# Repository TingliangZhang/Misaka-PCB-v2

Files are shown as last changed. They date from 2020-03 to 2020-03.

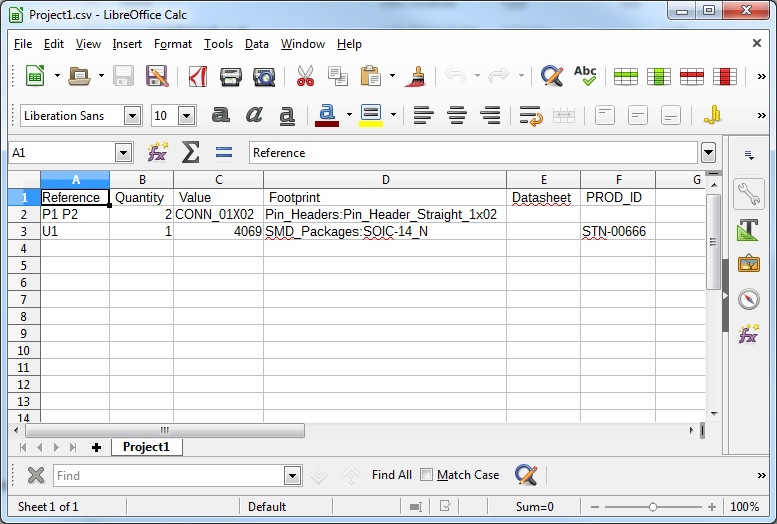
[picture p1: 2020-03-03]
KiCAD Lib/SparkFun-KiCad-Libraries/Tools/SparkFun-Eagle-Libraries_Conversion/generatedBOM.jpg

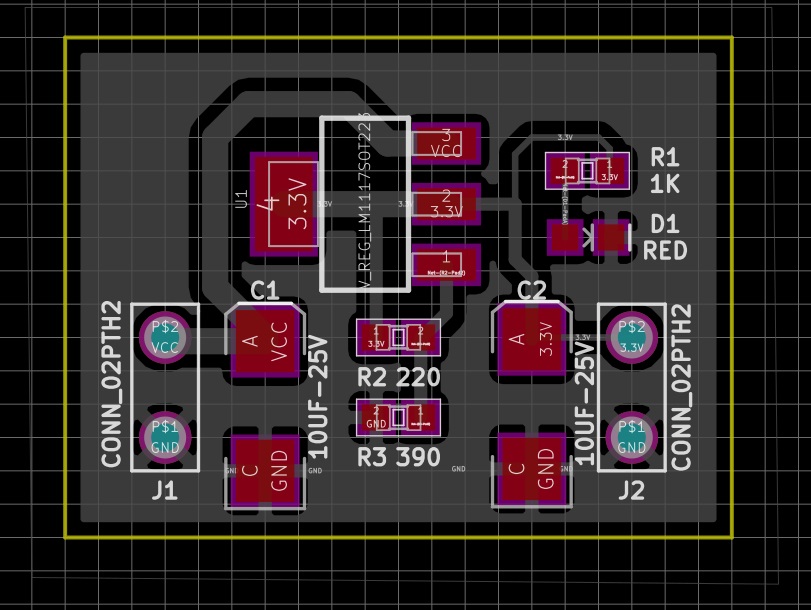
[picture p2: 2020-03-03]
KiCAD Lib/SparkFun-KiCad-Libraries/Tools/SparkFun-Eagle-Libraries_Conversion/example4.jpg

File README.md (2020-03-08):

# Misaka-PCB-v2

Second Version of [TingliangZhang](https://github.com/TingliangZhang)/**[Misaka-PCB](https://github.com/TingliangZhang/Misaka-PCB)**

Using [KiCad EDA](https://kicad-pcb.org/)

插件安装等参考TUNA的帮助：

https://mirrors.tuna.tsinghua.edu.cn/help/kicad/

## CSV File (BOM)

需要将 ; 批量替换成 , 

## Keyboard commands - hotkeys

Many commands are accessible directly with the keyboard. Selection can be either upper or lower case. Most hot keys are shown in menus. Some hot keys that do not appear are:

- `Delete`: deletes a footprint or a track. (*Available only if the Footprint mode or the Track mode is active*)
- `V`: if the track tool is active switches working layer or place via, if a track is in progress.
- `+` and `-`: select next or previous layer.
- `?`: display the list of all hot keys.
- `Space`: reset relative coordinates.

## Third Party Libraries

In addition to the official KiCad libraries, there are other, third party sources for KiCad library packages.

While the following links may be useful sources of library packages, they are not maintained or endorsed by the KiCad project.

### Digi-Key

[Digi-Key](https://www.digikey.com/) maintains an atomic parts library for KiCad on their [GitHub page](https://github.com/digikey/digikey-kicad-library/). These libraries are licensed under an agreement similar to the official libraries.

### SparkFun

[SparkFun Electronics](https://sparkfun.com/) provide KiCad library files for many of their products on their [GitHub page](https://github.com/sparkfun/SparkFun-KiCad-Libraries). These libraries are based on the SparkFun Eagle libraries.

### SnapEDA

[SnapEDA](https://www.snapeda.com/) provides KiCad symbol and footprint libraries for their customers. The libraries are freely available and can be found on their [KiCad library page](https://www.snapeda.com/kicad). The library license can be found on their [terms of service page](https://www.snapeda.com/about/terms).

### Import Steps For KiCad 5 and Newer

https://www.snapeda.com/

1. In KiCad, go to *Tools > Edit PCB Footprints*.
2. Click on *Preferences > Manage Footprint Libraries*.

#### *For version 5.0*

In the *Global Libraries* tab, click on *Browse Libraries* and navigate to the downloaded folder after unzipping the .zip file. Then click *OK*.

1. Click on *Load footprint from library > Select by Browser*.
2. Navigate to the library folder you imported.
3. Double-click on the footprint to open it.

#### *For version 5.1*

In the *Global Libraries* tab, click on *Add existing library to table*, the small folder icon, and navigate to the downloaded folder after unzipping the .zip file. Then click *OK*.

1. Go to the libraries menu on the left side.
2. Navigate to the library folder you imported.
3. Click on it to open the drop-down menu and double-click on the footprint.

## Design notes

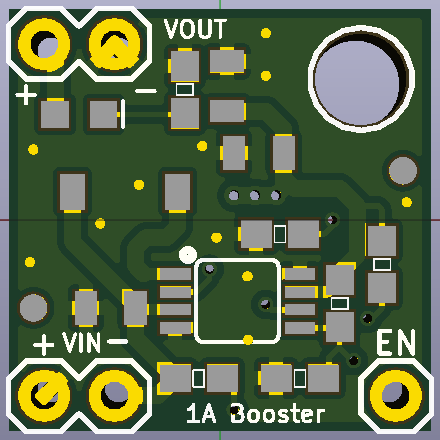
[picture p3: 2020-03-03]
KiCAD Lib/SparkFun-KiCad-Libraries/Documentation/Pictures/ExampleGreen3DView.png

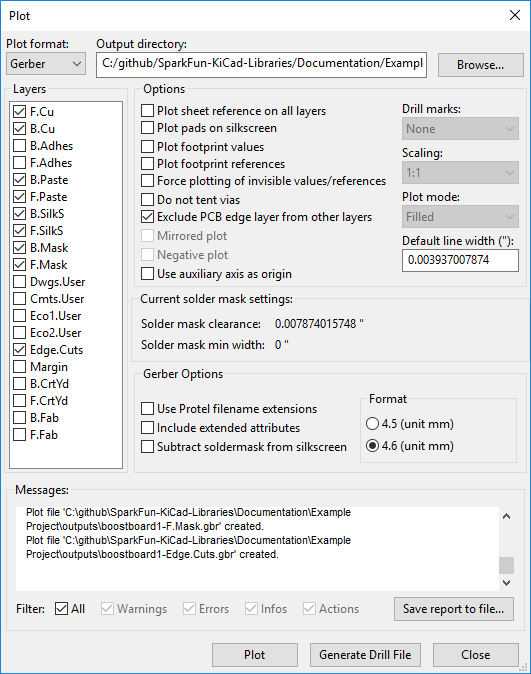
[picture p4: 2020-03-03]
KiCAD Lib/SparkFun-KiCad-Libraries/Documentation/Pictures/PlotSettings.png

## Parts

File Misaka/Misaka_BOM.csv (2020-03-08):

Comment | Description | Designator | Footprint | LibRef | Pins | Quantity | PartNumber | url
22pF | desc | C13, | C_0603_1608Metric_Pad1.05x0.95mm_HandSolder | libref | 2 | 1
1uF | desc | C16,C15, | C_0603_1608Metric_Pad1.05x0.95mm_HandSolder | libref | 2 | 2
100nF | desc | C24,C23,C22,C21,C20,C19,C18,C17,C14,C12,C11,C10, | C_0603_1608Metric_Pad1.05x0.95mm_HandSolder | libref | 2 | 12
47uF | desc | CP5,CP4, | CP_Elec_6.3x5.8 | libref | 2 | 2
CD1206 | desc | D1, | D_1206_3216Metric_Pad1.42x1.75mm_HandSolder | libref | 2 | 1
WS2812B | desc | D10,D9,D8,D7,D6,D5,D4,D3, | LED_WS2812B_PLCC4_5.0x5.0mm_P3.2mm | libref | 4 | 8
M7 | desc | D2, | D_SMA_Handsoldering | libref | 2 | 1
10k | desc | R23, | R_0603_1608Metric_Pad1.05x0.95mm_HandSolder | libref | 2 | 1
1M | desc | R26, | R_0603_1608Metric_Pad1.05x0.95mm_HandSolder | libref | 2 | 1
4.7k | desc | R32,R31,R30,R29, | R_0603_1608Metric_Pad1.05x0.95mm_HandSolder | libref | 2 | 4
1k | desc | R35,R34,R33,R28,R25,R24,R22, | R_0603_1608Metric_Pad1.05x0.95mm_HandSolder | libref | 2 | 7
TACTILE_SWITCH_SMD_4.5MM | desc | S1, | TACTILE_SWITCH_SMD_4.5MM | libref | 4 | 1
LED | desc | TX1,RX1,L1, | LED_0603_1608Metric_Pad1.05x0.95mm_HandSolder | libref | 2 | 3
ATmega2560-16AU | desc | U2, | TQFP-100_14x14mm_P0.5mm | libref | 100 | 1
CH340C | desc | U5, | SOIC-16_3.9x9.9mm_P1.27mm | libref | 16 | 1
AMS1117-5.0 | desc | U6, | SOT-223-3_TabPin2 | libref | 4 | 1
AMS1117-3.3 | desc | U7, | SOT-223-3_TabPin2 | libref | 4 | 1
0.1uF | desc | C-VMB3,C-VMB2,C-VMB1,C-VMA3,C-VMA2,C-VMA1,C8,C5,C2, | C_0603_1608Metric_Pad1.05x0.95mm_HandSolder | libref | 2 | 9
0.01uF | desc | C7,C4,C1, | C_0603_1608Metric_Pad1.05x0.95mm_HandSolder | libref | 2 | 3
0.47uF | desc | C9,C6,C3, | C_0603_1608Metric_Pad1.05x0.95mm_HandSolder | libref | 2 | 3
100uF | desc | CP3,CP2,CP1, | CP_EIA-3528-21_Kemet-B_Pad1.50x2.35mm_HandSolder | libref | 2 | 3
50K | desc | R15,R8,R2, | R_0603_1608Metric_Pad1.05x0.95mm_HandSolder | libref | 2 | 3
30K | desc | R16,R9,R3, | R_0603_1608Metric_Pad1.05x0.95mm_HandSolder | libref | 2 | 3
1M | desc | R17,R10,R1, | R_0603_1608Metric_Pad1.05x0.95mm_HandSolder | libref | 2 | 3
10K | desc | R21,R20,R14,R13,R7,R6, | R_0603_1608Metric_Pad1.05x0.95mm_HandSolder | libref | 2 | 6
200m | desc | R4,R19,R18,R12,R11,R5, | R_0603_1608Metric_Pad1.05x0.95mm_HandSolder | libref | 2 | 6
SW_DIP_x03 | desc | SW1, | SW_DIP_SPSTx03_Slide_6.7x9.18mm_W8.61mm_P2.54mm_LowProfile | libref | 6 | 1
Through Hole Items
Conn_02x03_Odd_Even | desc | ICSP1, | PinHeader_2x03_P2.54mm_Vertical | libref | 6 | 1
Conn_Coaxial_Power | desc | J1, | AMASS_XT30PW-M_1x02_P2.50mm_Horizontal | libref | 4 | 1
USB_B_Micro | desc | J5, | USB_Micro-B_Wuerth_614105150721_Vertical | libref | 7 | 1
Conn_01x04_Female | desc | J6, | PinHeader_1x04_P2.54mm_Vertical | libref | 4 | 1
Conn_01x04_Female_UART | desc | J7, | PinSocket_1x04_P2.54mm_Vertical | libref | 4 | 1
Conn_01x07 | desc | J9, | PinSocket_1x07_P2.54mm_Vertical | libref | 7 | 1
XB24CZ7PIT-004 | desc | MOD1, | XBEE_PRO-20_THT | libref | 20 | 1
24LC02 | desc | U8, | DIP-8_W7.62mm_Socket_LongPads | libref | 8 | 1
CSTLS16M0X51-B0 | desc | Y1, | Resonator_muRata_CSTLSxxxX-3Pin_W5.5mm_H3.0mm | libref | 3 | 1
Conn_01x04_Male | desc | J4,J3,J2, | Molex_PicoBlade_53047-0410_1x04_P1.25mm_Vertical | libref | 4 | 3
Conn_02x04_Odd_Even | desc | J8, | PinSocket_2x04_P1.27mm_Vertical | libref | 8 | 1
DRV8825PWPR | desc | U4,U3,U1, | HTSSOP-28-1EP_4.4x9.7mm_P0.65mm_EP3.4x9.5mm_ThermalVias | libref | 58 | 3

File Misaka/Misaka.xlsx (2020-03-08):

Prj: | Misaka.xml |  |  |  |  |  | Board Qty: | 100
Co.: |  |  |  |  |  |  | Unit Cost: | $0.00
Prj date: | 08/03/2020 16:31:49 |  |  |  |  |  | Total Cost: | $0.00 |  |  |  | $0.00 | 0 |  |  |  | $0.00 | 0 |  |  |  | $0.00 | 0 |  |  |  | $0.00 | 0 |  |  |  | $0.00 | 0 |  |  |  | $0.00 | 0
$ date: | 2020-03-08 16:35:06
Global Part Info |  |  |  |  |  |  |  |  | Digi-Key |  |  |  |  | Farnell |  |  |  |  | LCSC |  |  |  |  | Mouser |  |  |  |  | Newark |  |  |  |  | RS Components
Refs | Value | Desc | Footprint | Manf | Manf# | Qty | Unit$ | Ext$ | Avail | Purch | Unit$ | Ext$ | Cat# | Avail | Purch | Unit$ | Ext$ | Cat# | Avail | Purch | Unit$ | Ext$ | Cat# | Avail | Purch | Unit$ | Ext$ | Cat# | Avail | Purch | Unit$ | Ext$ | Cat# | Avail | Purch | Unit$ | Ext$ | Cat#
C1,C4,C7 | 0.01uF |  | C_0603_1608Metric_Pad1.05x0.95mm_HandSolder |  |  | 0 | $0.00 | $0.00
C13 | 22pF |  | C_0603_1608Metric_Pad1.05x0.95mm_HandSolder |  |  | 0 | $0.00 | $0.00
C15,C16 | 1uF |  | C_0603_1608Metric_Pad1.05x0.95mm_HandSolder |  |  | 0 | $0.00 | $0.00
C2,C5,C8,C-VMA1-C-VMA3,C-VMB1-C-VMB3 | 0.1uF |  | C_0603_1608Metric_Pad1.05x0.95mm_HandSolder |  |  | 0 | $0.00 | $0.00
C3,C6,C9 | 0.47uF |  | C_0603_1608Metric_Pad1.05x0.95mm_HandSolder |  |  | 0 | $0.00 | $0.00
C10-C12,C14,C17-C24 | 100nF |  | C_0603_1608Metric_Pad1.05x0.95mm_HandSolder |  |  | 0 | $0.00 | $0.00
CP4,CP5 | 47uF |  | CP_Elec_6.3x5.8 |  |  | 0 | $0.00 | $0.00
CP1-CP3 | 100uF |  | CP_EIA-3528-21_Kemet-B_Pad1.50x2.35mm_HandSolder |  |  | 0 | $0.00 | $0.00
D1 | CD1206 |  | D_1206_3216Metric_Pad1.42x1.75mm_HandSolder |  |  | 0 | $0.00 | $0.00
D2 | M7 |  | D_SMA_Handsoldering |  |  | 0 | $0.00 | $0.00
D3-D10 | WS2812B |  | LED_WS2812B_PLCC4_5.0x5.0mm_P3.2mm |  |  | 0 | $0.00 | $0.00
ICSP1 | Conn_02x03_Odd_Even |  | PinHeader_2x03_P2.54mm_Vertical |  |  | 0 | $0.00 | $0.00
J1 | Conn_Coaxial_Power |  | AMASS_XT30PW-M_1x02_P2.50mm_Horizontal |  |  | 0 | $0.00 | $0.00
J5 | USB_B_Micro |  | USB_Micro-B_Wuerth_614105150721_Vertical |  |  | 0 | $0.00 | $0.00
J6 | Conn_01x04_Female |  | PinHeader_1x04_P2.54mm_Vertical |  |  | 0 | $0.00 | $0.00
J7 | Conn_01x04_Female_UART |  | PinSocket_1x04_P2.54mm_Vertical |  |  | 0 | $0.00 | $0.00
J8 | Conn_02x04_Odd_Even |  | PinSocket_2x04_P1.27mm_Vertical |  |  | 0 | $0.00 | $0.00
J9 | Conn_01x07 |  | PinSocket_1x07_P2.54mm_Vertical |  |  | 0 | $0.00 | $0.00
J2-J4 | Conn_01x04_Male |  | Molex_PicoBlade_53047-0410_1x04_P1.25mm_Vertical |  |  | 0 | $0.00 | $0.00
MOD1 | XB24CZ7PIT-004 | RF TXRX MOD 802.15.4 TRACE ANT | XBEE_PRO-20_THT | Digi International | XB24CZ7PIT-004 (https://www.digi.com/resources/documentation/digidocs/pdfs/90001500.pdf) | 0 | $0.00 | $0.00
R1,R10,R17,R26 | 1M |  | R_0603_1608Metric_Pad1.05x0.95mm_HandSolder |  |  | 0 | $0.00 | $0.00
R2,R8,R15 | 50K |  | R_0603_1608Metric_Pad1.05x0.95mm_HandSolder |  |  | 0 | $0.00 | $0.00
R22,R24,R25,R28,R33-R35 | 1k |  | R_0603_1608Metric_Pad1.05x0.95mm_HandSolder |  |  | 0 | $0.00 | $0.00
R23 | 10k |  | R_0603_1608Metric_Pad1.05x0.95mm_HandSolder |  |  | 0 | $0.00 | $0.00
R3,R9,R16 | 30K |  | R_0603_1608Metric_Pad1.05x0.95mm_HandSolder |  |  | 0 | $0.00 | $0.00
R4,R5,R11,R12,R18,R19 | 200m |  | R_0603_1608Metric_Pad1.05x0.95mm_HandSolder |  |  | 0 | $0.00 | $0.00
R6,R7,R13,R14,R20,R21 | 10K |  | R_0603_1608Metric_Pad1.05x0.95mm_HandSolder |  |  | 0 | $0.00 | $0.00
R29-R32 | 4.7k |  | R_0603_1608Metric_Pad1.05x0.95mm_HandSolder |  |  | 0 | $0.00 | $0.00
S1 | TACTILE_SWITCH_SMD_4.5MM |  | TACTILE_SWITCH_SMD_4.5MM |  |  | 0 | $0.00 | $0.00
SW1 | SW_DIP_x03 |  | SW_DIP_SPSTx03_Slide_6.7x9.18mm_W8.61mm_P2.54mm_LowProfile |  |  | 0 | $0.00 | $0.00
TX1,L1,RX1 | LED |  | LED_0603_1608Metric_Pad1.05x0.95mm_HandSolder |  |  | 0 | $0.00 | $0.00
U1,U3,U4 | DRV8825PWPR | IC MTR DRVR BIPLR 8.2-45V 28SSOP | HTSSOP-28-1EP_4.4x9.7mm_P0.65mm_EP3.4x9.5mm_ThermalVias | Texas Instruments | DRV8825PWPR | 0 | $0.00 | $0.00
U2 | ATmega2560-16AU |  | TQFP-100_14x14mm_P0.5mm |  | http://ww1.microchip.com/downloads/en/DeviceDoc/Atmel-2549-8-bit-AVR-Microcontroller-ATmega640-1280-1281-2560-2561_datasheet.pdf | 0 | $0.00 | $0.00
U5 | CH340C |  | SOIC-16_3.9x9.9mm_P1.27mm |  | http://www.datasheet5.com/pdf-local-2195953 | 0 | $0.00 | $0.00
U6 | AMS1117-5.0 |  | SOT-223-3_TabPin2 |  |  | 0 | $0.00 | $0.00
U7 | AMS1117-3.3 |  | SOT-223-3_TabPin2 |  |  | 0 | $0.00 | $0.00
U8 | 24LC02 |  | DIP-8_W7.62mm_Socket_LongPads |  | http://ww1.microchip.com/downloads/en/DeviceDoc/21709c.pdf | 0 | $0.00 | $0.00
Y1 | CSTLS16M0X51-B0 |  | Resonator_muRata_CSTLSxxxX-3Pin_W5.5mm_H3.0mm |  |  | 0 | $0.00 | $0.00
 |  |  |  |  |  |  | Total Purchase: | $0.00 |  | 0 |  | $0.00 |  |  | 0 |  | $0.00 |  |  | 0 |  | $0.00 |  |  | 0 |  | $0.00 |  |  | 0 |  | $0.00 |  |  | 0 |  | $0.00
KiCost® v.1.1.3 |  |  |  |  |  |  | Purchase description: |  |  | 0 |  |  |  |  | 0 |  |  |  |  | 0 |  |  |  |  | 0 |  |  |  |  | 0 |  |  |  |  | 0
 |  |  |  |  |  |  |  |  |  | 0 |  |  |  |  | 0 |  |  |  |  | 0 |  |  |  |  | 0 |  |  |  |  | 0 |  |  |  |  | 0
 |  |  |  |  |  |  |  |  |  | 0 |  |  |  |  | 0 |  |  |  |  | 0 |  |  |  |  | 0 |  |  |  |  | 0 |  |  |  |  | 0
 |  |  |  |  |  |  |  |  |  | 0 |  |  |  |  | 0 |  |  |  |  | 0 |  |  |  |  | 0 |  |  |  |  | 0 |  |  |  |  | 0
 |  |  |  |  |  |  |  |  |  | 0 |  |  |  |  | 0 |  |  |  |  | 0 |  |  |  |  | 0 |  |  |  |  | 0 |  |  |  |  | 0
 |  |  |  |  |  |  |  |  |  | 0 |  |  |  |  | 0 |  |  |  |  | 0 |  |  |  |  | 0 |  |  |  |  | 0 |  |  |  |  | 0
 |  |  |  |  |  |  |  |  |  | 0 |  |  |  |  | 0 |  |  |  |  | 0 |  |  |  |  | 0 |  |  |  |  | 0 |  |  |  |  | 0
 |  |  |  |  |  |  |  |  |  | 0 |  |  |  |  | 0 |  |  |  |  | 0 |  |  |  |  | 0 |  |  |  |  | 0 |  |  |  |  | 0
 |  |  |  |  |  |  |  |  |  | 0 |  |  |  |  | 0 |  |  |  |  | 0 |  |  |  |  | 0 |  |  |  |  | 0 |  |  |  |  | 0
 |  |  |  |  |  |  |  |  |  | 0 |  |  |  |  | 0 |  |  |  |  | 0 |  |  |  |  | 0 |  |  |  |  | 0 |  |  |  |  | 0
 |  |  |  |  |  |  |  |  |  | 0 |  |  |  |  | 0 |  |  |  |  | 0 |  |  |  |  | 0 |  |  |  |  | 0 |  |  |  |  | 0
 |  |  |  |  |  |  |  |  |  | 0 |  |  |  |  | 0 |  |  |  |  | 0 |  |  |  |  | 0 |  |  |  |  | 0 |  |  |  |  | 0
 |  |  |  |  |  |  |  |  |  | 0 |  |  |  |  | 0 |  |  |  |  | 0 |  |  |  |  | 0 |  |  |  |  | 0 |  |  |  |  | 0
 |  |  |  |  |  |  |  |  |  | 0 |  |  |  |  | 0 |  |  |  |  | 0 |  |  |  |  | 0 |  |  |  |  | 0 |  |  |  |  | 0
 |  |  |  |  |  |  |  |  |  | 0 |  |  |  |  | 0 |  |  |  |  | 0 |  |  |  |  | 0 |  |  |  |  | 0 |  |  |  |  | 0
 |  |  |  |  |  |  |  |  |  | 0 |  |  |  |  | 0 |  |  |  |  | 0 |  |  |  |  | 0 |  |  |  |  | 0 |  |  |  |  | 0
 |  |  |  |  |  |  |  |  |  | 0 |  |  |  |  | 0 |  |  |  |  | 0 |  |  |  |  | 0 |  |  |  |  | 0 |  |  |  |  | 0
 |  |  |  |  |  |  |  |  |  | 0 |  |  |  |  | 0 |  |  |  |  | 0 |  |  |  |  | 0 |  |  |  |  | 0 |  |  |  |  | 0
 |  |  |  |  |  |  |  |  |  | 0 |  |  |  |  | 0 |  |  |  |  | 0 |  |  |  |  | 0 |  |  |  |  | 0 |  |  |  |  | 0
 |  |  |  |  |  |  |  |  |  | 0 |  |  |  |  | 0 |  |  |  |  | 0 |  |  |  |  | 0 |  |  |  |  | 0 |  |  |  |  | 0
 |  |  |  |  |  |  |  |  |  | 0 |  |  |  |  | 0 |  |  |  |  | 0 |  |  |  |  | 0 |  |  |  |  | 0 |  |  |  |  | 0
 |  |  |  |  |  |  |  |  |  | 0 |  |  |  |  | 0 |  |  |  |  | 0 |  |  |  |  | 0 |  |  |  |  | 0 |  |  |  |  | 0
 |  |  |  |  |  |  |  |  |  | 0 |  |  |  |  | 0 |  |  |  |  | 0 |  |  |  |  | 0 |  |  |  |  | 0 |  |  |  |  | 0
 |  |  |  |  |  |  |  |  |  | 0 |  |  |  |  | 0 |  |  |  |  | 0 |  |  |  |  | 0 |  |  |  |  | 0 |  |  |  |  | 0
 |  |  |  |  |  |  |  |  |  | 0 |  |  |  |  | 0 |  |  |  |  | 0 |  |  |  |  | 0 |  |  |  |  | 0 |  |  |  |  | 0
 |  |  |  |  |  |  |  |  |  | 0 |  |  |  |  | 0 |  |  |  |  | 0 |  |  |  |  | 0 |  |  |  |  | 0 |  |  |  |  | 0
 |  |  |  |  |  |  |  |  |  | 0 |  |  |  |  | 0 |  |  |  |  | 0 |  |  |  |  | 0 |  |  |  |  | 0 |  |  |  |  | 0
 |  |  |  |  |  |  |  |  |  | 0 |  |  |  |  | 0 |  |  |  |  | 0 |  |  |  |  | 0 |  |  |  |  | 0 |  |  |  |  | 0
 |  |  |  |  |  |  |  |  |  | 0 |  |  |  |  | 0 |  |  |  |  | 0 |  |  |  |  | 0 |  |  |  |  | 0 |  |  |  |  | 0
 |  |  |  |  |  |  |  |  |  | 0 |  |  |  |  | 0 |  |  |  |  | 0 |  |  |  |  | 0 |  |  |  |  | 0 |  |  |  |  | 0
 |  |  |  |  |  |  |  |  |  | 0 |  |  |  |  | 0 |  |  |  |  | 0 |  |  |  |  | 0 |  |  |  |  | 0 |  |  |  |  | 0
 |  |  |  |  |  |  |  |  |  | 0 |  |  |  |  | 0 |  |  |  |  | 0 |  |  |  |  | 0 |  |  |  |  | 0 |  |  |  |  | 0
 |  |  |  |  |  |  |  |  |  | 0 |  |  |  |  | 0 |  |  |  |  | 0 |  |  |  |  | 0 |  |  |  |  | 0 |  |  |  |  | 0
 |  |  |  |  |  |  |  |  |  | 0 |  |  |  |  | 0 |  |  |  |  | 0 |  |  |  |  | 0 |  |  |  |  | 0 |  |  |  |  | 0
 |  |  |  |  |  |  |  |  |  | 0 |  |  |  |  | 0 |  |  |  |  | 0 |  |  |  |  | 0 |  |  |  |  | 0 |  |  |  |  | 0
 |  |  |  |  |  |  |  |  |  | 0 |  |  |  |  | 0 |  |  |  |  | 0 |  |  |  |  | 0 |  |  |  |  | 0 |  |  |  |  | 0
 |  |  |  |  |  |  |  |  |  | 0 |  |  |  |  | 0 |  |  |  |  | 0 |  |  |  |  | 0 |  |  |  |  | 0 |  |  |  |  | 0
 |  |  |  |  |  |  |  |  |  | 0 |  |  |  |  | 0 |  |  |  |  | 0 |  |  |  |  | 0 |  |  |  |  | 0 |  |  |  |  | 0
 |  |  |  |  |  |  |  |  |  |  |  |  |  |  |  |  |  |  |  | 0

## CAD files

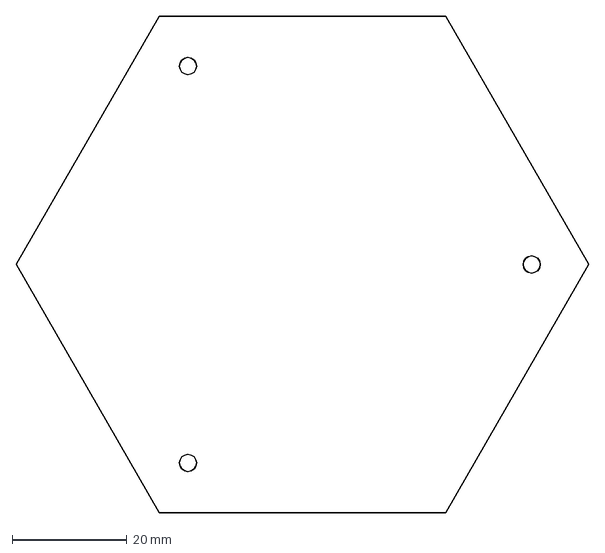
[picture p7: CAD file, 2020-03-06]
Misaka/PCB.dxf
100.0 x 86.6 mm

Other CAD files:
References/MEGA2560_Rev3/dimensioniMega.dxf

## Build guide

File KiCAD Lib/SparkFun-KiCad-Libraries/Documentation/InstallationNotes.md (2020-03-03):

Installation Notes
----------------

* [The KiCad site](http://kicad-pcb.org/)

**KiCad installation**

* Uninstall previous versions of KiCad
* Download KiCad stable version 4.0.5 from [http://kicad-pcb.org/download/](http://kicad-pcb.org/download/windows/) and install
* After install, you'll be prompted to install "Wings 3D", check this box to be redirected to [http://www.wings3d.com/](http://www.wings3d.com/)
* Download and install the stable release 2.1.5

**Using the libraries**

* Create a local project (this is necessary because projects hold library path information)
* Open the "Schematic Library Editor"
* Prefrences -> Component Libraries
  * Remove all libraries from list
  * Add -> navigate to SparkFun-KiCad-Libraries -> select all .lib files -> open, then hit OK
  * Test by selecting an active library.  All sparkfun libraries should be displayed.  Close the library editor
* Open the "PCB Footprint Editor"
* Preferences -> Footprint Library Manager
  * Remove all (if any) libraries, hit OK
* Preferences -> Footprint Libraries Wizard
  * Next (files on my computer)
  * Navigate to SparkFun-KiCad-Libraries -> select all .mod files and hit ok
  * Next
  * Select for this project only
  * Next
  * Close the editor
* Save the project (Green arrow into extern HDD icon, no menu exists)

Now, this project is linked to the libraries.  Open a schematic and place components.  See KiCad enginursday post for converting from schematic into board (Note: You need to have nets for this to work... not just unconnected components)

**License Information**

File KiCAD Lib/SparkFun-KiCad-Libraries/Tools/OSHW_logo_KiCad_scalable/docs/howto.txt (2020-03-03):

How to make your own:
---------------------

Watch / read this first:

* http://www.kicad-pcb.org/display/KICAD/Videos+by+zupnikal

The last two videos should be helpful for how to create a custom .emp file from images.

* http://www.re-innovation.co.uk/web12/index.php/en/blog-75/230-adding-logo-to-kicad

If you use linux (which you should), you don't have to use the online-scaler. Just use the scripts!

---

* Create a folder to hold your new footprint library.
* Copy the scripts 'make_lib.sh' and 'scale.pl' into that folder.
* Make sure these files are executable (chmod u+x ...).
* Copy your custom .emp file into that foler.

* Run the 'make_lib.sh' script as follows:

./make_lib.sh input-file.emp lib-name.mod START END

START and END are placeholders for positive integer numbers (1,2,3...) that determine
the range of created footprint sizes. The units are metric (mm).

The 'lib-name.mod' file will show up in the 'lib' sub-folder. Add it to your pcbnew
library settings as usual.

Footprints that are created for back-layers are automagically mirrored horizontally.
To place them onto a back-layer, hover the mouse-pointer over them and press 'f' for 'flip'.

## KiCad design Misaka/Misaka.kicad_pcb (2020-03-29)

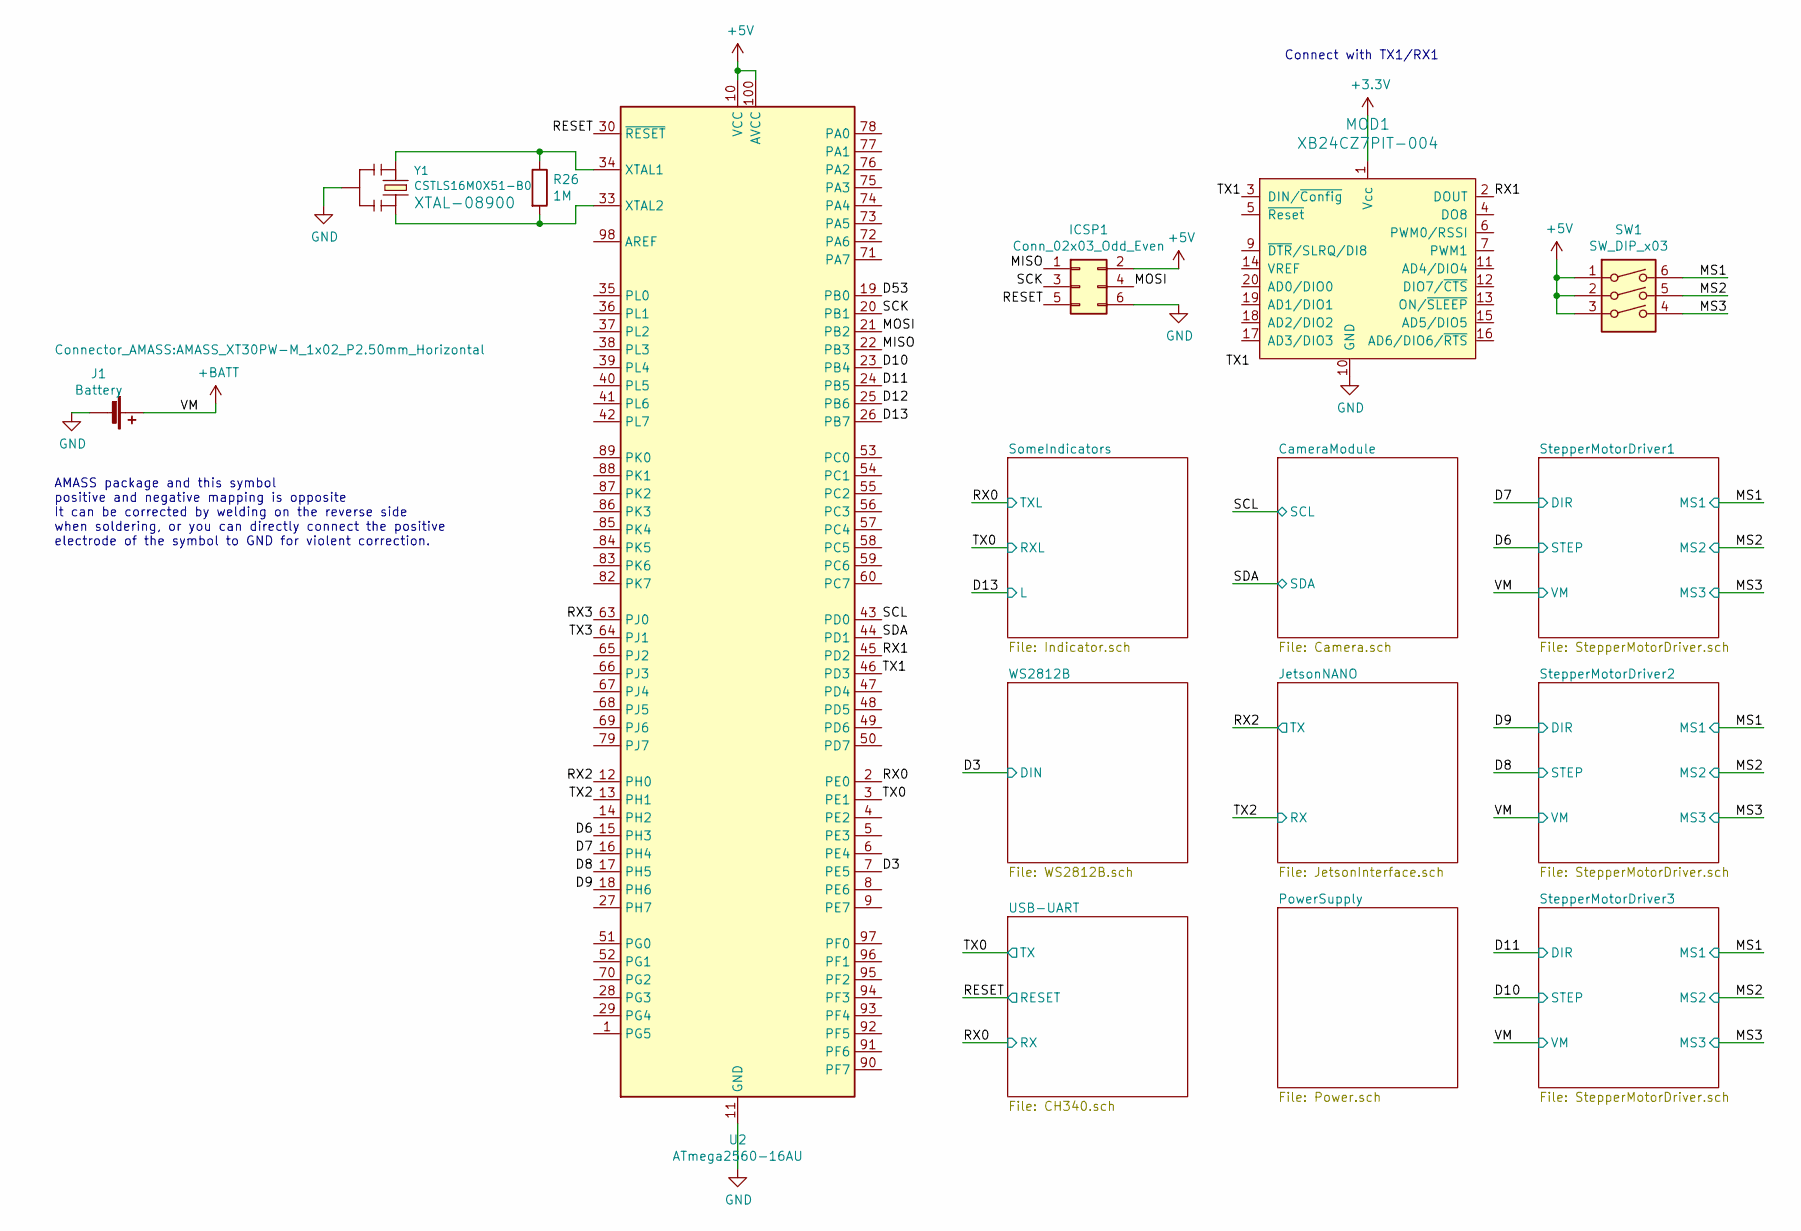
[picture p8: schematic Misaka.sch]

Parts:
ICSP1: Conn_02x03_Odd_Even; PinHeader_2x03_P2.54mm_Vertical
J1: Battery; AMASS_XT30PW-M_1x02_P2.50mm_Horizontal
MOD1: XB24CZ7PIT-004; XBEE_PRO-20_THT; MPN XB24CZ7PIT-004; Digi-Key_PN 602-1557-ND
R26: 1M; R_0603_1608Metric_Pad1.05x0.95mm_HandSolder
SW1: SW_DIP_x03; SW_DIP_SPSTx03_Slide_6.7x9.18mm_W8.61mm_P2.54mm_LowProfile
U2: ATmega2560-16AU; TQFP-100_14x14mm_P0.5mm
Y1: CSTLS16M0X51-B0; Resonator_muRata_CSTLSxxxX-3Pin_W5.5mm_H3.0mm

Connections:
+3V3: MOD1.1 (Vcc); also elsewhere on the board
+5V: ICSP1.2, SW1.1, SW1.2, SW1.3, U2.10 (VCC), U2.31 (VCC), U2.61 (VCC), U2.80 (VCC), U2.100 (AVCC); also elsewhere on the board
+12V: J1.1 (+); also elsewhere on the board
/D3: U2.7 (PE5); also elsewhere on the board
/D6: U2.15 (PH3); also elsewhere on the board
/D7: U2.16 (PH4); also elsewhere on the board
/D8: U2.17 (PH5); also elsewhere on the board
/D9: U2.18 (PH6); also elsewhere on the board
/D10: U2.23 (PB4); also elsewhere on the board
/D11: U2.24 (PB5); also elsewhere on the board
/D13: U2.26 (PB7); also elsewhere on the board
/MISO: ICSP1.1, U2.22 (PB3)
/MOSI: ICSP1.4, U2.21 (PB2)
/MS1: SW1.6; also elsewhere on the board
/MS2: SW1.5; also elsewhere on the board
/MS3: SW1.4; also elsewhere on the board
/RESET: ICSP1.5, U2.30 (~RESET); also elsewhere on the board
/RX0: U2.2 (PE0); also elsewhere on the board
/RX1: MOD1.2 (DOUT), U2.45 (PD2)
/RX2: U2.12 (PH0); also elsewhere on the board
/SCK: ICSP1.3, U2.20 (PB1)
/SCL: U2.43 (PD0); also elsewhere on the board
/SDA: U2.44 (PD1); also elsewhere on the board
/TX0: U2.3 (PE1); also elsewhere on the board
/TX1: MOD1.3 (DIN/~Config), U2.46 (PD3)
/TX2: U2.13 (PH1); also elsewhere on the board
GND: ICSP1.6, J1.2 (-), MOD1.10 (GND), U2.11 (GND), U2.32 (GND), U2.62 (GND), U2.81 (GND), U2.99 (GND), Y1.2; also elsewhere on the board
unnamed: R26.1, U2.34 (XTAL1), Y1.1
unnamed: R26.2, U2.33 (XTAL2), Y1.3

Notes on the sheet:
Connect with TX1/RX1
AMASS package and this symbol positive and negative mapping is opposite It can be corrected by welding on the reverse side when soldering, or you can directly connect the positive electrode of the symbol to GND for violent correction.

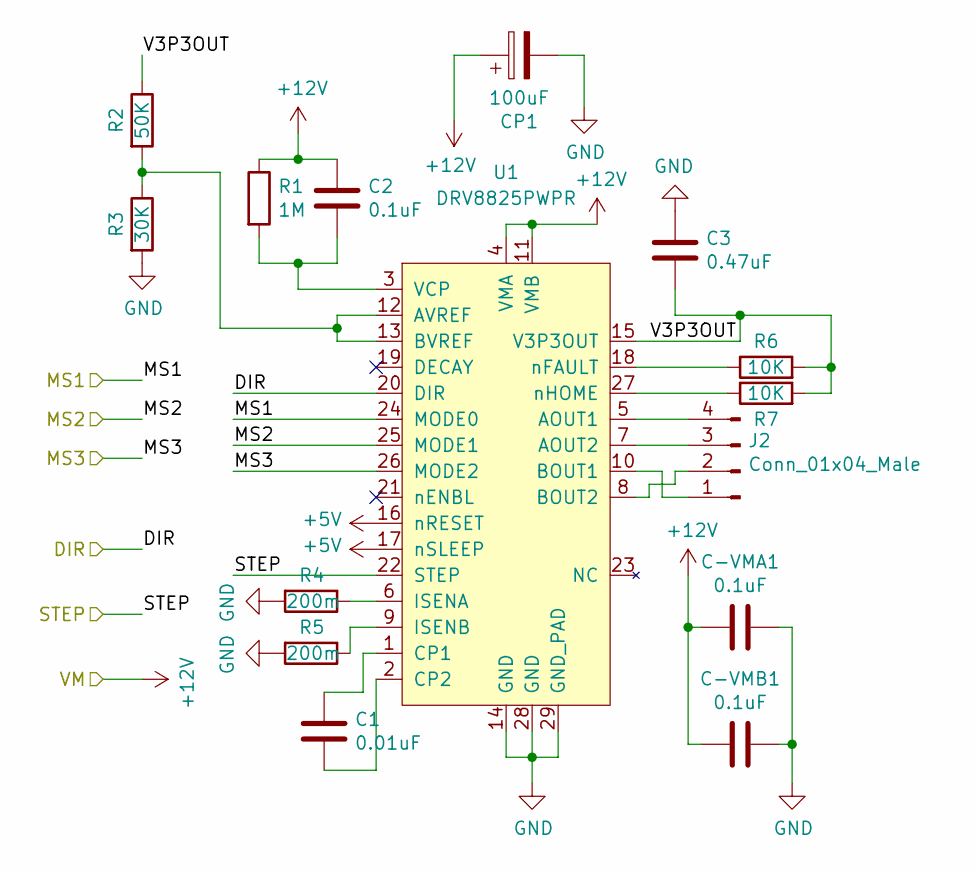
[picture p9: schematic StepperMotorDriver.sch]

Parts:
C1: 0.01uF; C_0603_1608Metric_Pad1.05x0.95mm_HandSolder
C2: 0.1uF; C_0603_1608Metric_Pad1.05x0.95mm_HandSolder
C3: 0.47uF; C_0603_1608Metric_Pad1.05x0.95mm_HandSolder
C-VMA1: 0.1uF; C_0603_1608Metric_Pad1.05x0.95mm_HandSolder
C-VMB1: 0.1uF; C_0603_1608Metric_Pad1.05x0.95mm_HandSolder
CP1: 100uF; CP_EIA-3528-21_Kemet-B_Pad1.50x2.35mm_HandSolder
J2: Conn_01x04_Male; Molex_PicoBlade_53047-0410_1x04_P1.25mm_Vertical
R1: 1M; R_0603_1608Metric_Pad1.05x0.95mm_HandSolder
R2: 50K; R_0603_1608Metric_Pad1.05x0.95mm_HandSolder
R3: 30K; R_0603_1608Metric_Pad1.05x0.95mm_HandSolder
R4, R5: 200m; R_0603_1608Metric_Pad1.05x0.95mm_HandSolder
R6, R7: 10K; R_0603_1608Metric_Pad1.05x0.95mm_HandSolder
U1: DRV8825PWPR; HTSSOP-28-1EP_4.4x9.7mm_P0.65mm_EP3.4x9.5mm_ThermalVias

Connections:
+5V: U1.16 (nRESET), U1.17 (nSLEEP); also elsewhere on the board
+12V: C2.1, C-VMA1.2, C-VMB1.2, CP1.1, R1.1, U1.4 (VMA), U1.11 (VMB); also elsewhere on the board
/D6: U1.22 (STEP); also elsewhere on the board
/D7: U1.20 (DIR); also elsewhere on the board
/MS1: U1.24 (MODE0); also elsewhere on the board
/MS2: U1.25 (MODE1); also elsewhere on the board
/MS3: U1.26 (MODE2); also elsewhere on the board
/StepperMotorDriver1/V3P3OUT: C3.2, R2.1, R6.2, R7.2, U1.15 (V3P3OUT)
GND: C3.1, C-VMA1.1, C-VMB1.1, CP1.2, R3.2, R4.2, R5.2, U1.14 (GND), U1.28 (GND), U1.29 (GND_PAD); also elsewhere on the board
unnamed: C1.1, U1.1 (CP1)
unnamed: C1.2, U1.2 (CP2)
unnamed: C2.2, R1.2, U1.3 (VCP)
unnamed: J2.1, U1.10 (BOUT1)
unnamed: J2.2, U1.8 (BOUT2)
unnamed: J2.3, U1.7 (AOUT2)
unnamed: J2.4, U1.5 (AOUT1)
unnamed: R2.2, R3.1, U1.12 (AVREF), U1.13 (BVREF)
unnamed: R4.1, U1.6 (ISENA)
unnamed: R5.1, U1.9 (ISENB)
unnamed: R6.1, U1.18 (nFAULT)
unnamed: R7.1, U1.27 (nHOME)

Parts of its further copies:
C4, C7: 0.01uF; C_0603_1608Metric_Pad1.05x0.95mm_HandSolder
C5, C8: 0.1uF; C_0603_1608Metric_Pad1.05x0.95mm_HandSolder
C6, C9: 0.47uF; C_0603_1608Metric_Pad1.05x0.95mm_HandSolder
C-VMA2, C-VMA3: 0.1uF; C_0603_1608Metric_Pad1.05x0.95mm_HandSolder
C-VMB2, C-VMB3: 0.1uF; C_0603_1608Metric_Pad1.05x0.95mm_HandSolder
CP2, CP3: 100uF; CP_EIA-3528-21_Kemet-B_Pad1.50x2.35mm_HandSolder
J3, J4: Conn_01x04_Male; Molex_PicoBlade_53047-0410_1x04_P1.25mm_Vertical
R8, R15: 50K; R_0603_1608Metric_Pad1.05x0.95mm_HandSolder
R9, R16: 30K; R_0603_1608Metric_Pad1.05x0.95mm_HandSolder
R10, R17: 1M; R_0603_1608Metric_Pad1.05x0.95mm_HandSolder
R11, R12, R18, R19: 200m; R_0603_1608Metric_Pad1.05x0.95mm_HandSolder
R13, R14, R20, R21: 10K; R_0603_1608Metric_Pad1.05x0.95mm_HandSolder
U3, U4: DRV8825PWPR; HTSSOP-28-1EP_4.4x9.7mm_P0.65mm_EP3.4x9.5mm_ThermalVias

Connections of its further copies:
+5V: U3.16 (nRESET), U3.17 (nSLEEP), U4.16 (nRESET), U4.17 (nSLEEP); also elsewhere on the board
+12V: C5.1, C8.1, C-VMA2.2, C-VMA3.2, C-VMB2.2, C-VMB3.2, CP2.1, CP3.1, R10.1, R17.1, U3.4 (VMA), U3.11 (VMB), U4.4 (VMA), U4.11 (VMB); also elsewhere on the board
/D8: U3.22 (STEP); also elsewhere on the board
/D9: U3.20 (DIR); also elsewhere on the board
/D10: U4.22 (STEP); also elsewhere on the board
/D11: U4.20 (DIR); also elsewhere on the board
/MS1: U3.24 (MODE0), U4.24 (MODE0); also elsewhere on the board
/MS2: U3.25 (MODE1), U4.25 (MODE1); also elsewhere on the board
/MS3: U3.26 (MODE2), U4.26 (MODE2); also elsewhere on the board
/StepperMotorDriver2/V3P3OUT: C6.2, R8.1, R13.2, R14.2, U3.15 (V3P3OUT)
/StepperMotorDriver3/V3P3OUT: C9.2, R15.1, R20.2, R21.2, U4.15 (V3P3OUT)
GND: C6.1, C9.1, C-VMA2.1, C-VMA3.1, C-VMB2.1, C-VMB3.1, CP2.2, CP3.2, R9.2, R11.2, R12.2, R16.2, R18.2, R19.2, U3.14 (GND), U3.28 (GND), U3.29 (GND_PAD), U4.14 (GND), U4.28 (GND), U4.29 (GND_PAD); also elsewhere on the board
unnamed: C4.1, U3.1 (CP1)
unnamed: C4.2, U3.2 (CP2)
unnamed: C5.2, R10.2, U3.3 (VCP)
unnamed: C7.1, U4.1 (CP1)
unnamed: C7.2, U4.2 (CP2)
unnamed: C8.2, R17.2, U4.3 (VCP)
unnamed: J3.1, U3.10 (BOUT1)
unnamed: J3.2, U3.8 (BOUT2)
unnamed: J3.3, U3.7 (AOUT2)
unnamed: J3.4, U3.5 (AOUT1)
unnamed: J4.1, U4.10 (BOUT1)
unnamed: J4.2, U4.8 (BOUT2)
unnamed: J4.3, U4.7 (AOUT2)
unnamed: J4.4, U4.5 (AOUT1)
unnamed: R8.2, R9.1, U3.12 (AVREF), U3.13 (BVREF)
unnamed: R11.1, U3.6 (ISENA)
unnamed: R12.1, U3.9 (ISENB)
unnamed: R13.1, U3.18 (nFAULT)
unnamed: R14.1, U3.27 (nHOME)
unnamed: R15.2, R16.1, U4.12 (AVREF), U4.13 (BVREF)
unnamed: R18.1, U4.6 (ISENA)
unnamed: R19.1, U4.9 (ISENB)
unnamed: R20.1, U4.18 (nFAULT)
unnamed: R21.1, U4.27 (nHOME)

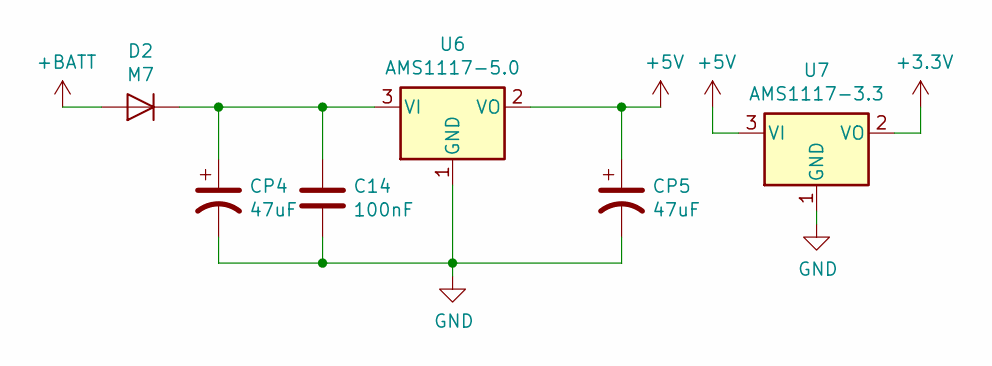
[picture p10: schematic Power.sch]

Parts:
C14: 100nF; C_0603_1608Metric_Pad1.05x0.95mm_HandSolder
CP4, CP5: 47uF; CP_Elec_6.3x5.8
D2: M7; D_SMA_Handsoldering
U6: AMS1117-5.0; SOT-223-3_TabPin2
U7: AMS1117-3.3; SOT-223-3_TabPin2

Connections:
+3V3: U7.2 (VO); also elsewhere on the board
+5V: CP5.1, U6.2 (VO), U7.3 (VI); also elsewhere on the board
+12V: D2.2 (A); also elsewhere on the board
GND: C14.2, CP4.2, CP5.2, U6.1 (GND), U7.1 (GND); also elsewhere on the board
unnamed: C14.1, CP4.1, D2.1 (K), U6.3 (VI)

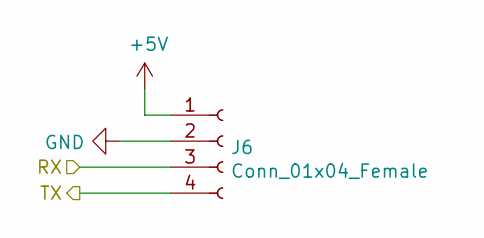
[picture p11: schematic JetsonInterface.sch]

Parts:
J6: Conn_01x04_Female; PinHeader_1x04_P2.54mm_Vertical

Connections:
+5V: J6.1; also elsewhere on the board
/RX2: J6.4; also elsewhere on the board
/TX2: J6.3; also elsewhere on the board
GND: J6.2; also elsewhere on the board

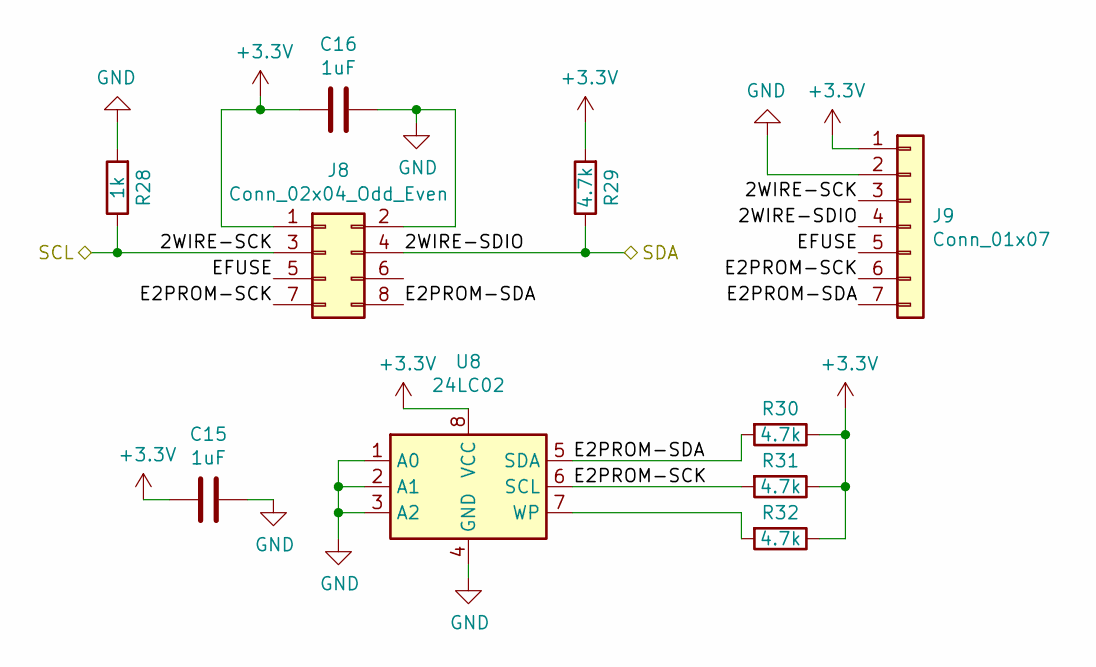
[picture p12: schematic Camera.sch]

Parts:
C15, C16: 1uF; C_0603_1608Metric_Pad1.05x0.95mm_HandSolder
J8: Conn_02x04_Odd_Even; PinSocket_2x04_P1.27mm_Vertical
J9: Conn_01x07; PinSocket_1x07_P2.54mm_Vertical
R28: 1k; R_0603_1608Metric_Pad1.05x0.95mm_HandSolder
R29, R30, R31, R32: 4.7k; R_0603_1608Metric_Pad1.05x0.95mm_HandSolder
U8: 24LC02; DIP-8_W7.62mm_Socket_LongPads

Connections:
+3V3: C15.2, C16.2, J8.1, J9.1, R29.2, R30.1, R31.1, R32.1, U8.8 (VCC); also elsewhere on the board
/CameraModule/E2PROM-SCK: J8.7, J9.6, R31.2, U8.6 (SCL)
/CameraModule/E2PROM-SDA: J8.8, J9.7, R30.2, U8.5 (SDA)
/CameraModule/EFUSE: J8.5, J9.5
/SCL: J8.3, J9.3, R28.1; also elsewhere on the board
/SDA: J8.4, J9.4, R29.1; also elsewhere on the board
GND: C15.1, C16.1, J8.2, J9.2, R28.2, U8.1 (A0), U8.2 (A1), U8.3 (A2), U8.4 (GND); also elsewhere on the board
unnamed: R32.2, U8.7 (WP)

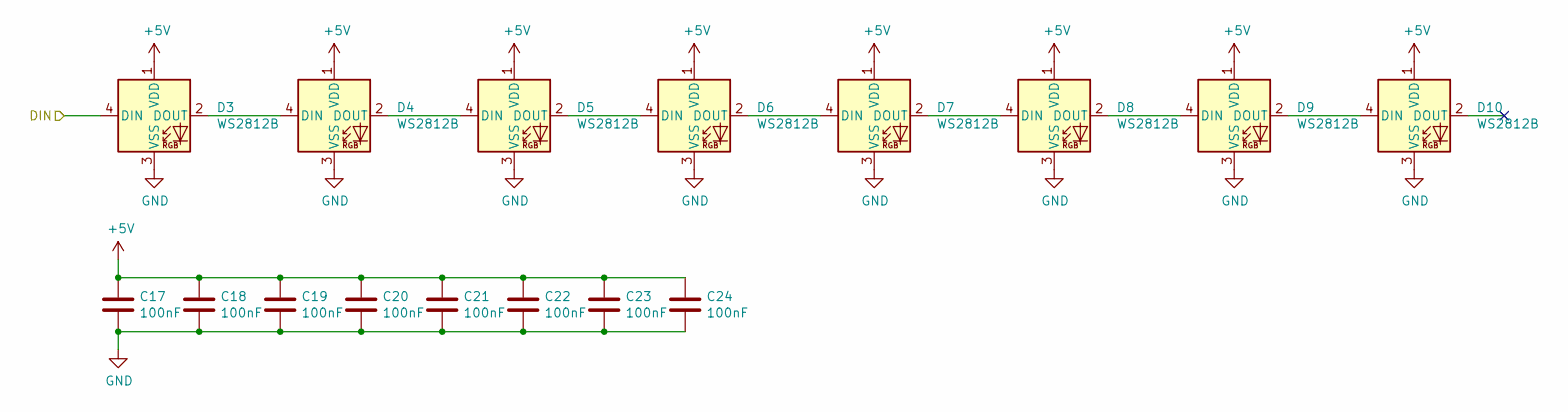
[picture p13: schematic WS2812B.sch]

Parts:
C17, C18, C19, C20, C21, C22, C23, C24: 100nF; C_0603_1608Metric_Pad1.05x0.95mm_HandSolder
D3, D4, D5, D6, D7, D8, D9, D10: WS2812B; LED_WS2812B_PLCC4_5.0x5.0mm_P3.2mm

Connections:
+5V: C17.1, C18.1, C19.1, C20.1, C21.1, C22.1, C23.1, C24.1, D3.1 (VDD), D4.1 (VDD), D5.1 (VDD), D6.1 (VDD), D7.1 (VDD), D8.1 (VDD), D9.1 (VDD), D10.1 (VDD); also elsewhere on the board
/D3: D3.4 (DIN); also elsewhere on the board
GND: C17.2, C18.2, C19.2, C20.2, C21.2, C22.2, C23.2, C24.2, D3.3 (VSS), D4.3 (VSS), D5.3 (VSS), D6.3 (VSS), D7.3 (VSS), D8.3 (VSS), D9.3 (VSS), D10.3 (VSS); also elsewhere on the board
unnamed: D3.2 (DOUT), D4.4 (DIN)
unnamed: D4.2 (DOUT), D5.4 (DIN)
unnamed: D5.2 (DOUT), D6.4 (DIN)
unnamed: D6.2 (DOUT), D7.4 (DIN)
unnamed: D7.2 (DOUT), D8.4 (DIN)
unnamed: D8.2 (DOUT), D9.4 (DIN)
unnamed: D9.2 (DOUT), D10.4 (DIN)

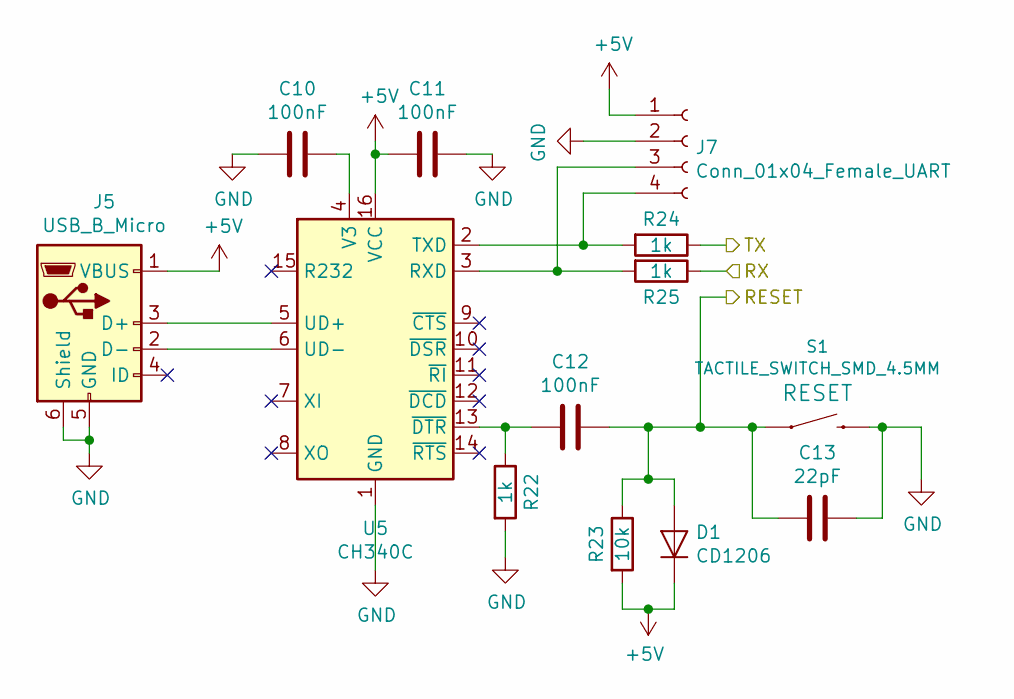
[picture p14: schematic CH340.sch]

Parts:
C10, C11, C12: 100nF; C_0603_1608Metric_Pad1.05x0.95mm_HandSolder
C13: 22pF; C_0603_1608Metric_Pad1.05x0.95mm_HandSolder
D1: CD1206; D_1206_3216Metric_Pad1.42x1.75mm_HandSolder
J5: USB_B_Micro; USB_Micro-B_Wuerth_614105150721_Vertical
J7: Conn_01x04_Female_UART; PinSocket_1x04_P2.54mm_Vertical
R22, R24, R25: 1k; R_0603_1608Metric_Pad1.05x0.95mm_HandSolder
R23: 10k; R_0603_1608Metric_Pad1.05x0.95mm_HandSolder
S1: TACTILE_SWITCH_SMD_4.5MM
U5: CH340C; SOIC-16_3.9x9.9mm_P1.27mm

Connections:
+5V: C11.2, D1.1 (K), J5.1 (VBUS), J7.1, R23.2, U5.16 (VCC); also elsewhere on the board
/RESET: C12.1, C13.2, D1.2 (A), R23.1, S1.2 (1), S1.3 (1); also elsewhere on the board
/RX0: R25.1; also elsewhere on the board
/TX0: R24.1; also elsewhere on the board
GND: C10.2, C11.1, C13.1, J5.5 (GND), J5.6 (Shield), J7.2, R22.2, S1.1 (2), S1.4 (2), U5.1 (GND); also elsewhere on the board
unnamed: C10.1, U5.4 (V3)
unnamed: C12.2, R22.1, U5.13 (~DTR)
unnamed: J5.2 (D-), U5.6 (UD-)
unnamed: J5.3 (D+), U5.5 (UD+)
unnamed: J7.3, R25.2, U5.3 (RXD)
unnamed: J7.4, R24.2, U5.2 (TXD)

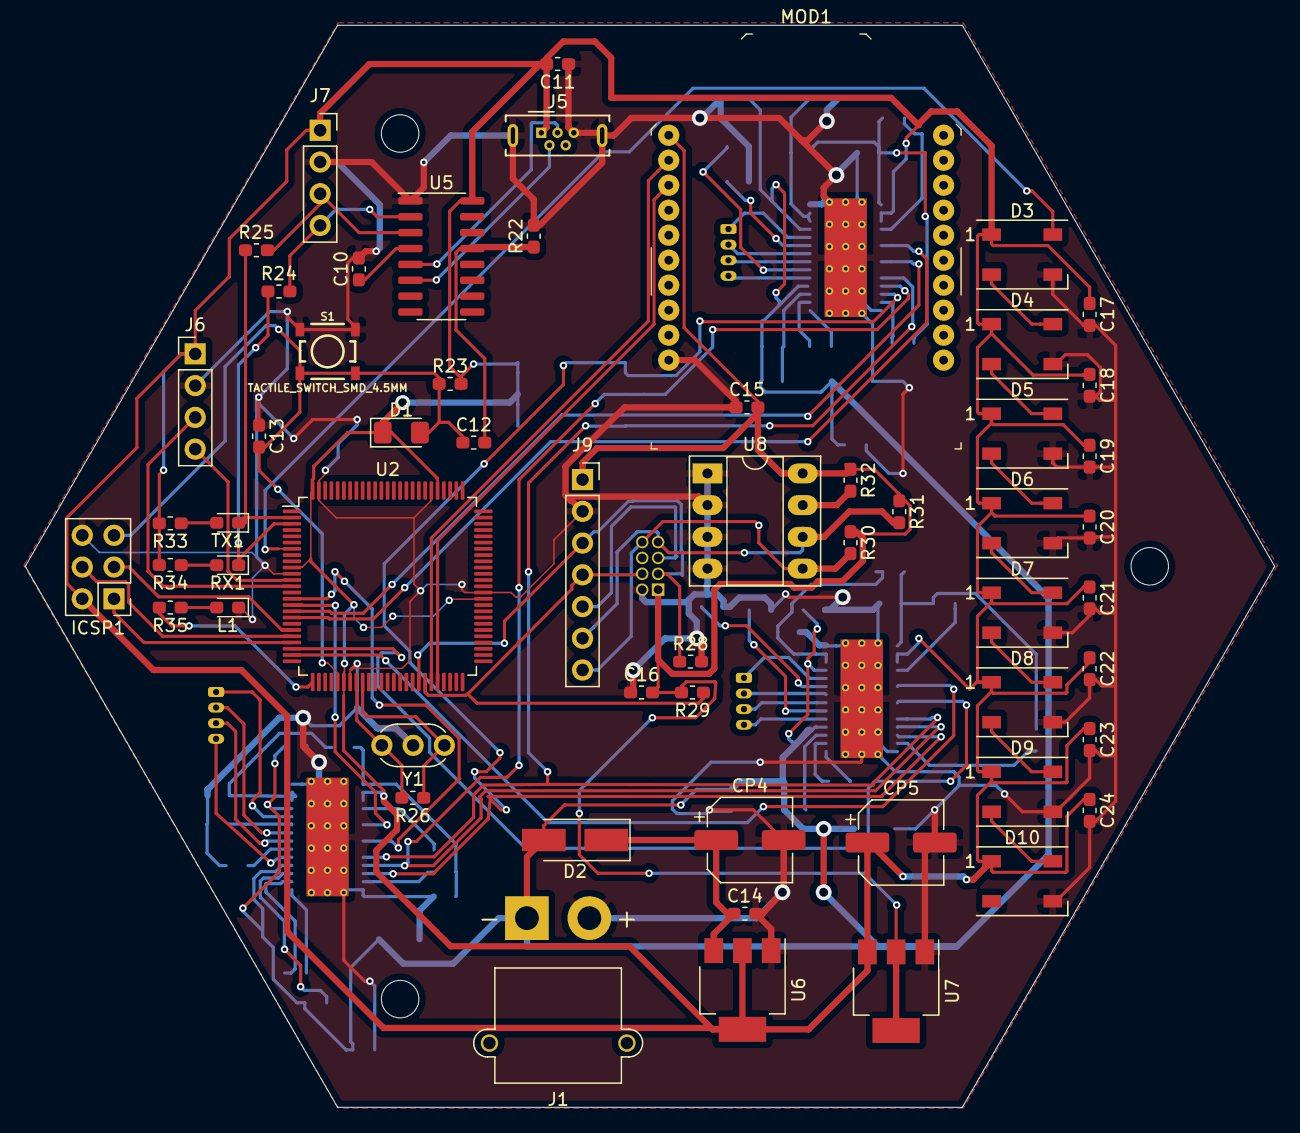
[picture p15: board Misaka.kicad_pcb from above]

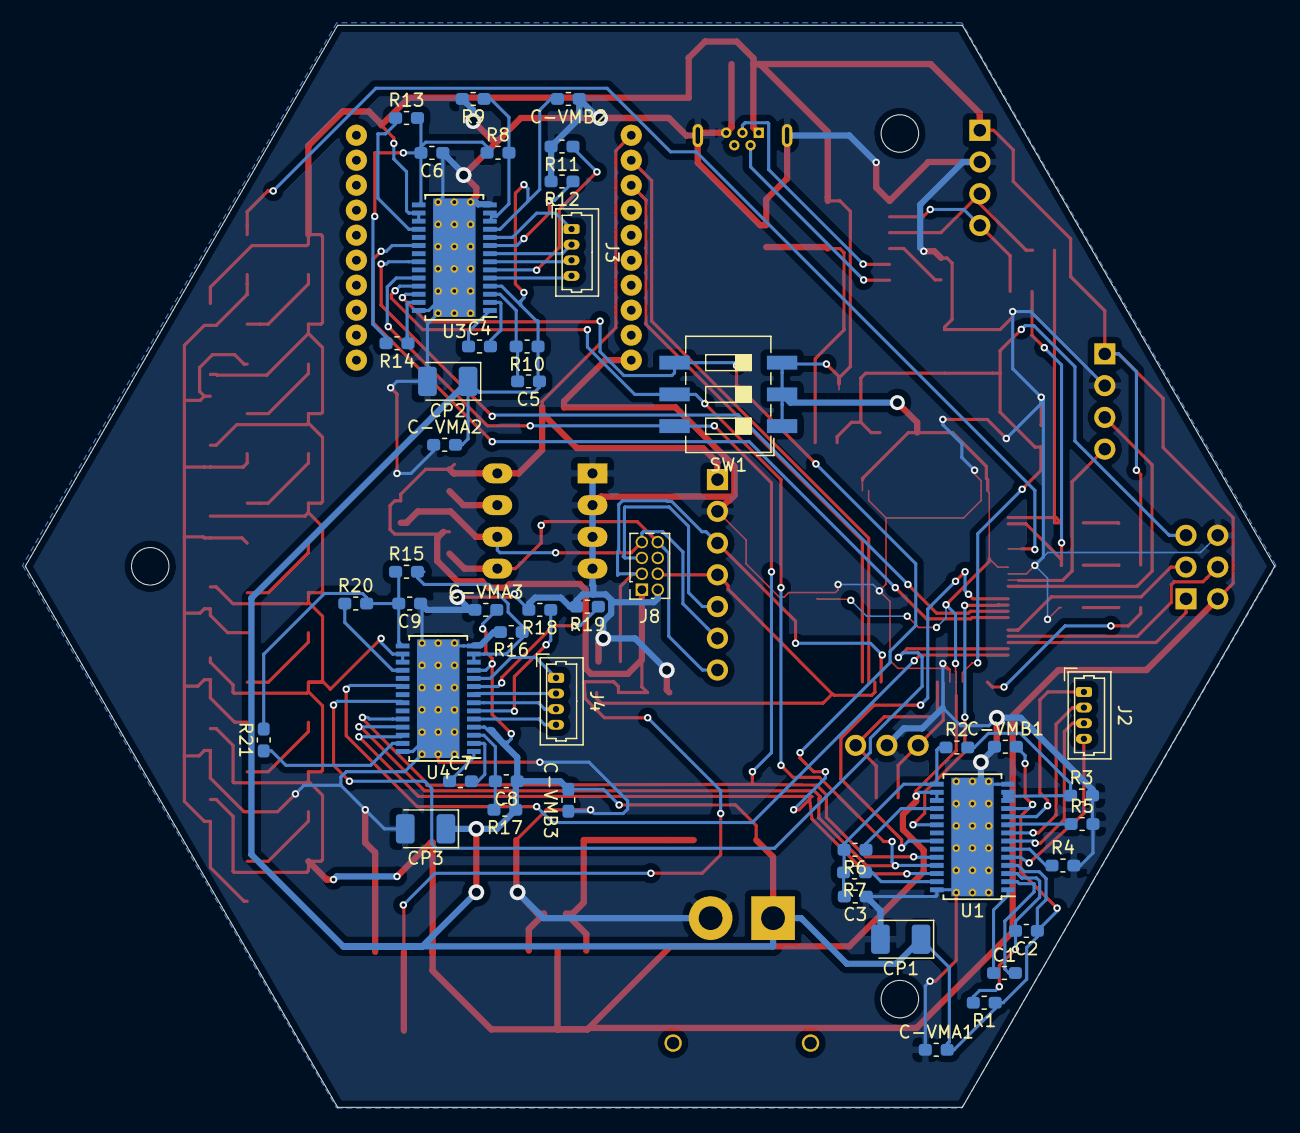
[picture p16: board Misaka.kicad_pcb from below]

Board: 2 copper layers, 100.0 x 86.6 mm, 104 parts (47 on the bottom side), 89 nets.

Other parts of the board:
L1: LED; LED_0603_1608Metric_Pad1.05x0.95mm_HandSolder
R33, R34, R35: 1k; R_0603_1608Metric_Pad1.05x0.95mm_HandSolder
RX1: LED; LED_0603_1608Metric_Pad1.05x0.95mm_HandSolder
TX1: LED; LED_0603_1608Metric_Pad1.05x0.95mm_HandSolder

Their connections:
+5V: R33.2, R34.2; also elsewhere on the board
/D13: R35.2; also elsewhere on the board
/RX0: TX1.1; also elsewhere on the board
/TX0: RX1.1; also elsewhere on the board
GND: L1.1; also elsewhere on the board
unnamed: L1.2, R35.1
unnamed: R33.1, TX1.2
unnamed: R34.1, RX1.2

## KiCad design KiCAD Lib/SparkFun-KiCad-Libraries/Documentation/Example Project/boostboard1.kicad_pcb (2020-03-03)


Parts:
C1, C2, C3: 22UF-0805-6.3V-20%; 0805
D1: LED-RED0603; LED-0603
FD1, FD2: FIDUCIAL1X2; FIDUCIAL-1X2
H1: STAND-OFF
J1, J3: CONN_02; 1X02
J2: CONN_01; 1X01
JP1: JUMPER-SMT_2_NO; SMT-JUMPER_2_NO_SILK
L1: INDUCTOR-CDRH-4.7UH; INDUCTOR_2.2UH
LOGO1: SFE_LOGO_NAME_FLAME.1_INCH; SFE_LOGO_NAME_FLAME_.1
LOGO2: OSHW-LOGOS; OSHW-LOGO-S
R1: 10KOHM-0603-1_10W-1%; 0603
R2, R4: 100KOHM-0603-1_10W-1%; 0603
R3, R5: 820KOHM-0603-1_10W-1%; 0603
R6: 4.7KOHM-0603-1_10W-1%; 0603
U1: PAM2401; MSOP8

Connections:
/EN: J2.1, R1.2, U1.2 (EN)
/FB: JP1.2, R3.1, R4.2, U1.5 (FB)
/GND: C1.2, C2.2, C3.2, J1.1, J3.1, R2.2, R4.1, R6.1, U1.4 (AGND), U1.8 (PGND)
/LX: L1.P$2 (2), U1.1 (LX)
/RSET: R2.1, U1.6 (RSET)
/VBATT: C1.1, J1.2, L1.P$1 (1), R1.1, U1.3 (VIN)
/VCC: C2.1, C3.1, D1.A, J3.2, R3.2, R5.2, U1.7 (OUT)
unnamed: D1.C, R6.2
unnamed: JP1.1, R5.1

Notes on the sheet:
1A Booster
Jumper: Open for 5.0V operation Closed for 3.3V operation
Input
Output
Input Range: 0.9 to 4.75V For full output capacity, upwards of 3A may be required. For max operation, calculate with P=IV, using 6 watts. At 3.7V, Iin = 1.62A



Board: 2 copper layers, 15.2 x 15.2 mm, 21 parts (3 on the bottom side), 9 nets.

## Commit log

2020-02-29 Ini DRV8825
    [DRV8825.kicad_pcb, DRV8825.sch]
2020-03-01 ROUTE DRV8825
    [DRV8825.sch]
2020-03-01 FINISH DRV8825
    [DRV8825.kicad_pcb, DRV8825.sch]
2020-03-01 FINISH AGAIN
    [DRV8825.sch]
2020-03-03 ADD Libraries
    [DRV8825-Digi-Key-Lib.kicad_pcb, DRV8825-Digi-Key-Lib.sch, _saved_boostboard1.sch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]
2020-03-04 Misaka ini
    [Misaka.kicad_pcb, Misaka.sch, StepperMotorDriver.sch]
2020-03-05 MURATA的 CSTLS16M0X51-A0
    [CH340.sch, JetsonInterface.sch, Misaka.sch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]
2020-03-05 route v1.0
    [Misaka.kicad_pcb]
2020-03-05 route v1.1
    [Misaka.kicad_pcb, Misaka.sch, StepperMotorDriver.sch]
2020-03-05 Begin Free Routing
    [Misaka.dsn, Misaka.kicad_pcb]
2020-03-05 Free Routing
    [Misaka.dsn]
2020-03-06 route v1.3
    [Misaka.kicad_pcb, PCB.dxf]
2020-03-06 Create Misaka - 副本.kicad_pcb
    [Misaka - 副本.kicad_pcb]
2020-03-06 change footprint to handsolding
    [Misaka-20200306-square.kicad_pcb, Misaka.kicad_pcb]
2020-03-06 route v2.0
    [Misaka.kicad_pcb]
2020-03-06 route v2.1
    [CH340.sch, Misaka.csv, Misaka.kicad_pcb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]
2020-03-06 Change Footprint
    [CH340.sch, Misaka.csv, Misaka.kicad_pcb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]
2020-03-06 route v2.2
    [CH340.sch, Misaka.kicad_pcb, Misaka.sch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]
2020-03-06 v2 finish
    [Misaka.kicad_pcb]
2020-03-08 KiCad EDA 生产文件生成器
    https://github.com/xtoolbox/kicad_tools
    [Misaka-Bottom_Cu.gbr, Misaka-Bottom_Mask.gbr, Misaka-Bottom_Paste.gbr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]
2020-03-23 电池正负极反了
    [Misaka.kicad_pcb, Misaka.sch]

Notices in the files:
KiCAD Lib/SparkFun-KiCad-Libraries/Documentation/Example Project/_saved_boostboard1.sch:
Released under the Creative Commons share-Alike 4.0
